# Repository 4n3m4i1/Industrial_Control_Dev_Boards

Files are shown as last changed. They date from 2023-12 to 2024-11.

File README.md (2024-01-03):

# Industrial_Control_Dev_Boards
For many projects a deeply embeddable development board is needed with the capability to take standard industrial DC voltages (12V, 24V, 36V) as input, and reliably provide outputs to anything else in a control/automation system. There aren't great options that support single side mounting (a la Pi Pico) that provide standard peripherals as well as CAN and possibly LIN, so here are some boards!  
  
## Board Families
- Waffle
The Waffle series is based on the F2800154QXXX (C2000 / dual TMS320C28x core) offerings from TI, which are generally aimed at the automotive market and thus provide good interfacing abilities for most controls needs. Several options are offered in the Waffle family (or rather, will, as my needs change) that only vary in pin count.
  
- Curly
The Curly series is based around the RP2040 we all know and love with an integrated TI TCAN4551-Q1 or MCP25625T-E_ML for SPI -> CAN conversion. These ICs include integrated CAN transceivers as well! Dual RS232 channels are provided from the boards, tied to the hardware UART peripherals.

- Tornado
Waiting on the new TI M0+ parts w CAN to drop... (MSPM0G)  
  
## Software Support
Once a design has been fabricated and verified boilerplate project templates will be included in each board's respective directory. Library files for on-board interfaceable components will be generally provided. Ensure required software is installed to reduce any compatability issues.
  
## Using Boards in Designs
Once a design has been fabricated and verified a footprint and symbol (KiCad 7) will be included in its respective library. These can be used as AIO components in other projects easily.
  
## Board Fabrication
Many PCBA services exist, and all fabrication files used to order a board will be provided in their respective directories. JLC's PCBA is unique in that their parts stock is in-house, which can be a massive bonus or immense drag depending on what you're trying to do. For my smaller scale their methods generally work, as long as parts selection is done to best fit their stock (and optimize for "Basic" parts over "Extended" parts, which incurr a proportionally large fee for small runs), as such certain choices have been made to optimize costs. Given their internal parts sourcing anyone can simply use the files provided, click "Buy", and assembled boards will show up at your house.
  
If a board is of interest, but you don't want to order it yourself, please contact me. If there is enough interest the fixed costs for setup and shipping can be reduced massively per board.

- Waffle Mini v0
Not verified.
  
- Curly Mini v0
All files provided for JLC PCBA, can be effectively one click ordered fully assembled. Approx. $45 for 5 complete boards, 1/2 parts, 1/2 setup fees, board costs are negligible. 2 day shipping to CA approx. $18.

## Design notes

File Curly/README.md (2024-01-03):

# Curly
The Curly series is based on the RP2040, which needs no introduction. The simplicity and open nature of the toolchain make this platform ideal in many respects, and the PIO can be leveraged heavily for custom peripheral creation.  
  
[Datasheet/Reference Manual](https://datasheets.raspberrypi.com/rp2040/rp2040-datasheet.pdf)
  
By default a single size of the Curly is offered.
  
## Curly Sizes
- Curly Mini
    - RP2040, 3V3 I/O
    - 44.5mm x 20mm x 1.6mm, 4 layer
    - Single side pinout for vertical mounting in PCB slot
    - 8 GPIO, 4 A2D / GPIO (Total 12) (AREF == 3.3V, not precision ref)
    - External Chip Reset Pin (Active Low)
    - 7V - 48V DC Input Voltage
    - Integrated CAN controller and transceiver (MCP25625T)
    - Integrated 2 channel RS232 converter (MAX3232)
    - NOT breadboard compatible, designed for custom vertical mounting in DIN enclosures
    - Custom 24 pin footprint + symbol provided in library
    - 3 pin Pico/ARM debug and programming interface
    - 3 pin USB 2.0 interface (D+, D-, GND) on header
    - For JLC/LCSC manufacturing the MCP25625T is used as it's more available

## Recommended Software
The `pico-sdk` toolchain should be installed, either via the repository ([pico-sdk](https://github.com/raspberrypi/pico-sdk)), or on Linux systems the clean setup script ([pico_setup.sh](https://github.com/raspberrypi/pico-setup/blob/master/pico_setup.sh)).  
  
## Programming
A standard ARM/Pico 3 pin (SWCLK, SWDIO, GND) JST connector is provided. Using a Pi Pico or other hardware to run picotool / OpenOCD `.elf` files can be loaded into the board, and GDB debugging can be done.
Picotool writeup will come soon...

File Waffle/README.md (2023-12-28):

# Waffle
The Waffle series is based on the F2800154Qxxx family of automotive processors centered around the TMS320C28x processors from TI. While dual core the default behavior is a lockstep mode with hardware comparisons done between each core in order to maintain a higher degree of safety. As with all things this can be customized in software, and disabled to allow full dual core operation if desired.

[Datasheet](https://www.ti.com/lit/gpn/tms320f2800154-q1)
[Reference Manual](https://www.ti.com/lit/ug/spruiy4a/spruiy4a.pdf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)
[Errata](https://www.ti.com/lit/er/sprz507b/sprz507b.pdf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)
  
Different Waffle sizes maintain similar feature sets, with varying amounts of GPIO. Each Waffle board has the following peripheral guaranteed:  
- 1 CAN2.0B / FD
- 3 UART
- 1 LIN
- 10+ PWM Channels

## Waffle Sizes
- Waffle Mini
	- F2800154QRHBRQ1, 20 GPIO
    - 35.56 mm x 17.78 mm
    - 1.4" x 0.7"
    - Breadboard compatible
    - Can be surface mounted w/ castelated pins (single side components)
    - Tag Connect 6 pin cJTAG interface (Odd Even Numbering)
        - 1: 3V3
        - 2: JTAG TMS
        - 3: XRSn (Reset)
        - 4: JTAG TCK
        - 5: GND
        - 6: N/C

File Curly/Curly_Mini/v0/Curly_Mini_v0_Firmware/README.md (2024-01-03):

# Curly Mini v0 Firmware
A boilerplate project with libraries to control the on-board CAN interface (MCP25625T) is provided. Ample use of the `pico-sdk` library functions has been done, please ensure this is properly installed.

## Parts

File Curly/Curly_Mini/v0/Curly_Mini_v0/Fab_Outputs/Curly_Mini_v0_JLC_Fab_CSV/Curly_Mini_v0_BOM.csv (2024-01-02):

Reference | Qty | Value | Footprint | LCSC Part Number
C1, C2, C6, C10, C12, C14, C16, C17, C18, C21, C23, C24, C25, C26, C27, C30, C31, C32, C33 | 19 | 100n | Capacitor_SMD:C_0402_1005Metric | C307331
C3, C4, C5, C9, C11, C13, C15, C19, C29, C34 | 10 | 2u2 | Capacitor_SMD:C_0402_1005Metric | C12530
C7, C8 | 2 | 33p C0G | Capacitor_SMD:C_0402_1005Metric | C1562
C20, C22 | 2 | 10u | Capacitor_SMD:C_0603_1608Metric | C96446
D1 | 1 | LED | LED_SMD:LED_0603_1608Metric | C72043
FB1 | 1 | FB_0603 | Inductor_SMD:L_0603_1608Metric | C1002
J1 | 1 | DEBUG_PORT | Connector_JST:JST_SH_BM03B-SRSS-TB_1x03-1MP_P1.00mm_Vertical | C160389
R1 | 1 | 5k1 | Resistor_SMD:R_0402_1005Metric | C25905
R2 | 1 | 1k 1% | Resistor_SMD:R_0402_1005Metric | C11702
R3, R4 | 2 | 27R | Resistor_SMD:R_0402_1005Metric | C25092
R5 | 1 | 330R | Resistor_SMD:R_0402_1005Metric | C25104
U1 | 1 | RP2040 | Package_DFN_QFN:QFN-56-1EP_7x7mm_P0.4mm_EP3.2x3.2mm | C2040
U2 | 1 | MCP25625T-E_ML | ICDB_Curly:QFN65P600X600X100-29N | C191253
U3 | 1 | XC6206PxxxMR | Package_TO_SOT_SMD:SOT-23-3 | C5446
U4 | 1 | W25Q16JVUXIQ_TR | ICDB_Curly:IC_W25Q16JVUXIQ_TR | C2843335
U5 | 1 | SE8650X2-HF | Package_TO_SOT_SMD:SOT-23-3 | C496615
U6 | 1 | MAX3232 | Package_SO:TSSOP-16_4.4x5mm_P0.65mm | C11317
Y2 | 1 | 12.000 MHz, C9002 | Crystal:Crystal_SMD_3225-4Pin_3.2x2.5mm | C9002

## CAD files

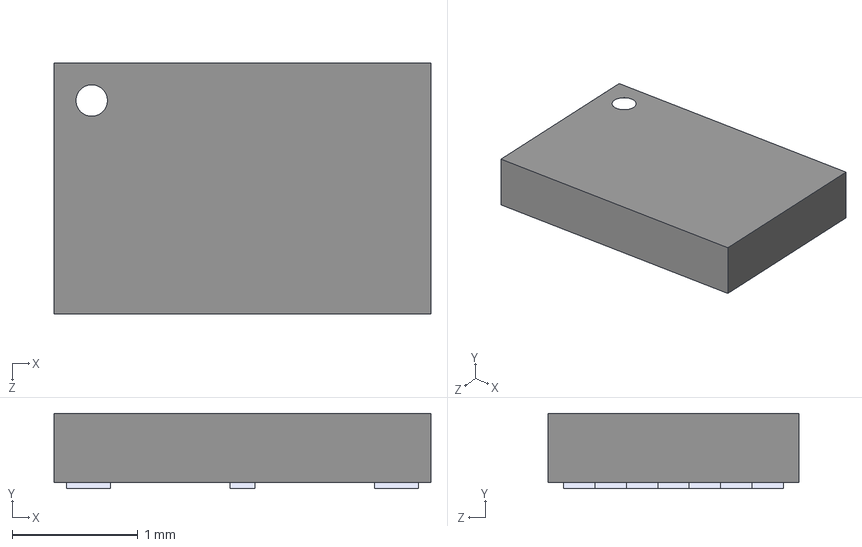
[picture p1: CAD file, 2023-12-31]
icdb_KiCad_7_Libs/ICDB_Curly/W25Q16JVUXIQ_TR.step
3.00 x 0.6 x 2.00 mm

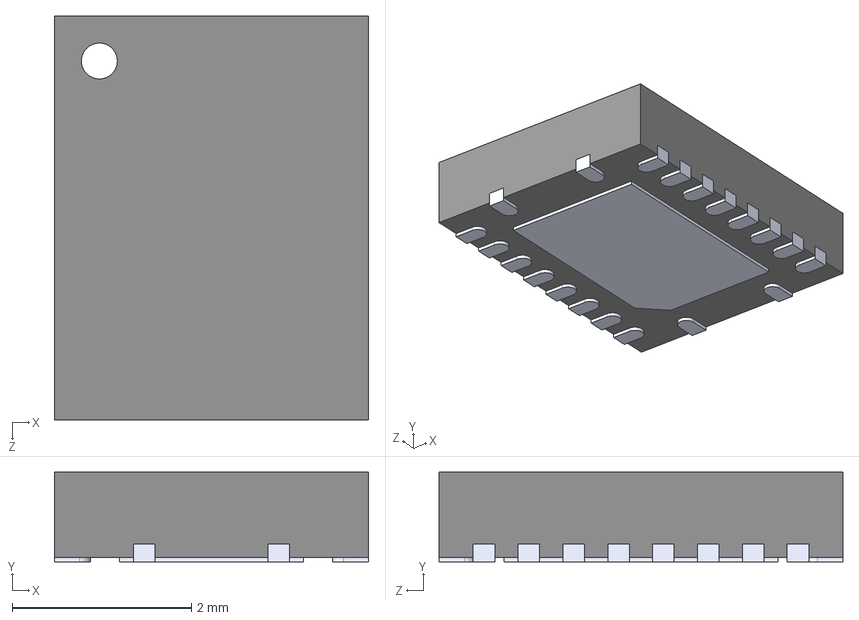
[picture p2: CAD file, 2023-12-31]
icdb_KiCad_7_Libs/ICDB_Curly/TCAN4550RGYRQ1.step
3.50 x 1.00 x 4.50 mm

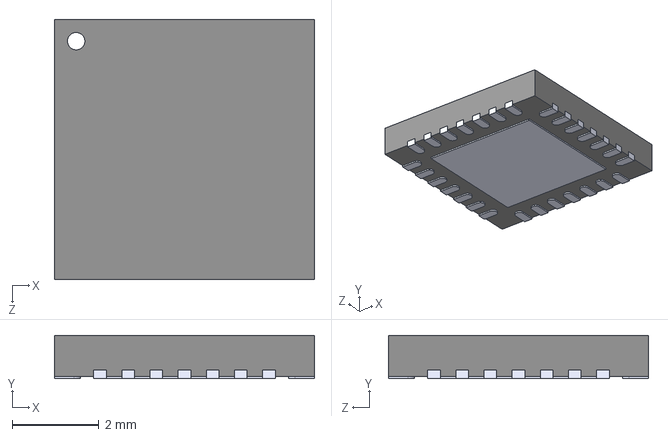
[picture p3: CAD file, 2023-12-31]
icdb_KiCad_7_Libs/ICDB_Curly/MCP25625T-E_ML.step
6.00 x 1.00 x 6.00 mm

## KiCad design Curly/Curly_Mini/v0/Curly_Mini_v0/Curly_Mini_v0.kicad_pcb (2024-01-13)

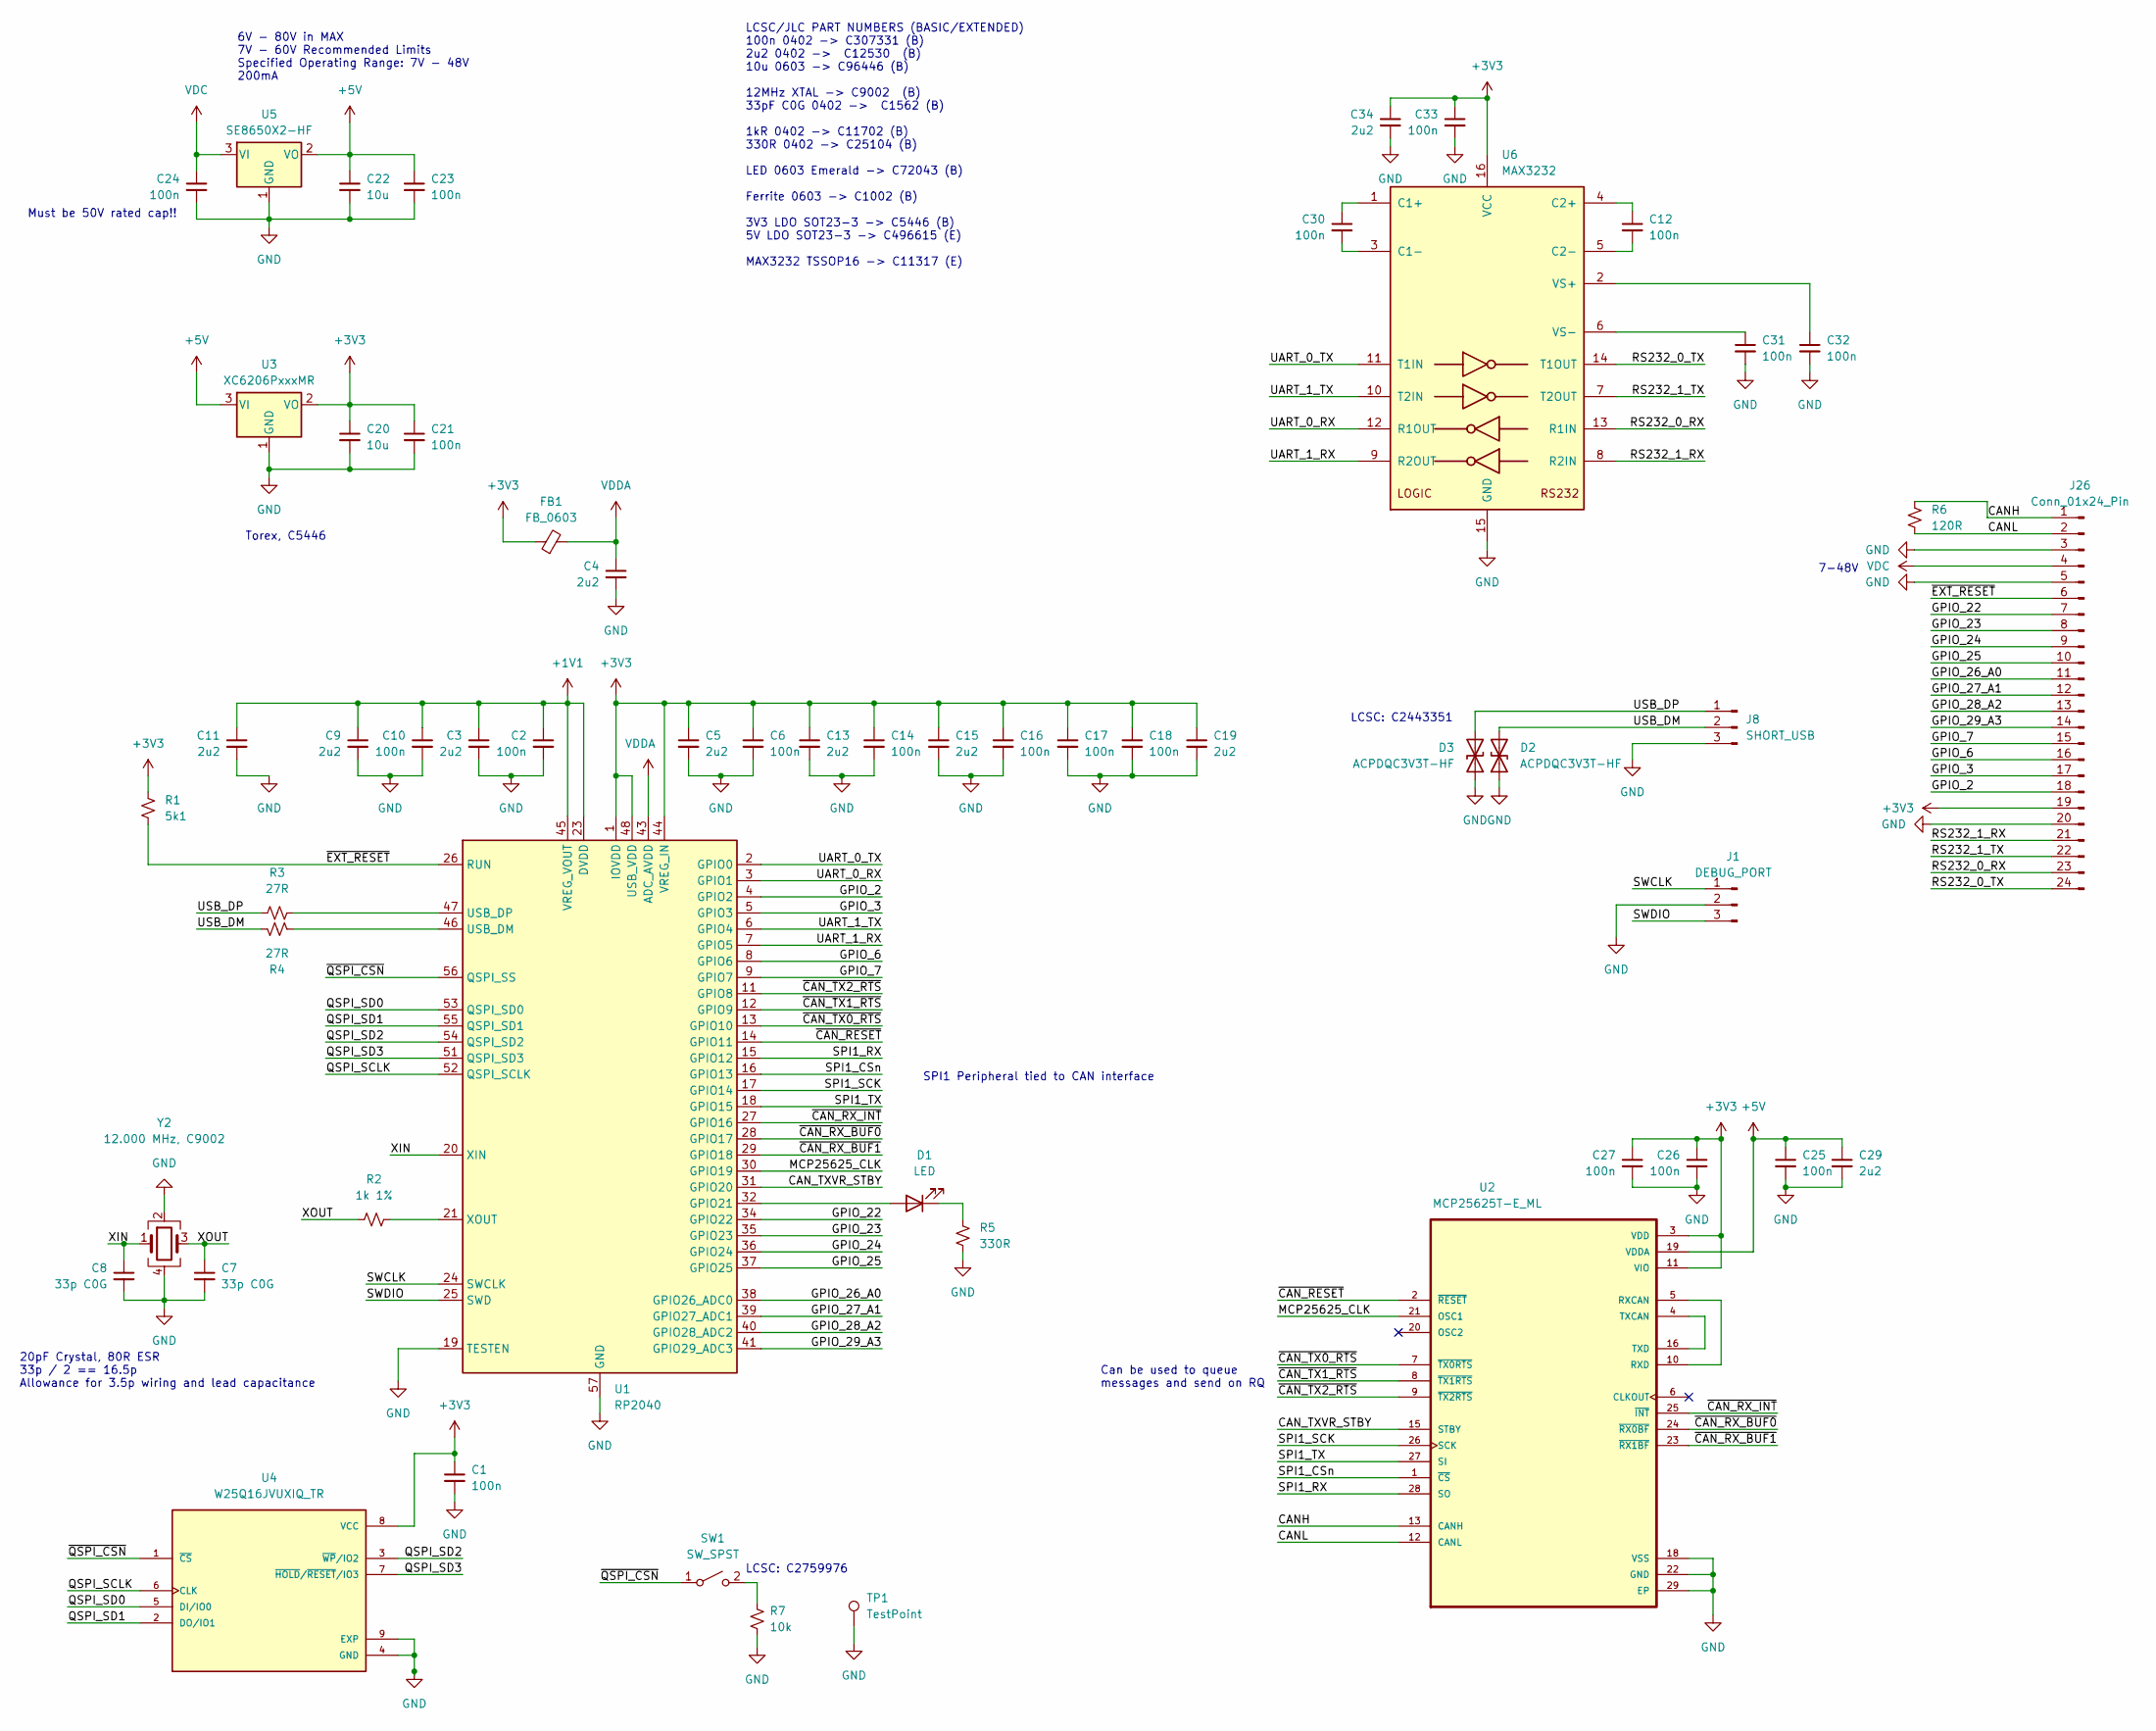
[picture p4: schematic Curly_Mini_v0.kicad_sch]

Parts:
C1, C2, C6, C10, C12, C14, C16, C17, C18, C21, C23, C24, C25, C26, C27, C30, C31, C32, C33: 100n; C_0402_1005Metric
C3, C4, C5, C9, C11, C13, C15, C19, C29, C34: 2u2; C_0402_1005Metric
C7, C8: 33p C0G; C_0402_1005Metric
C20, C22: 10u; C_0603_1608Metric
D1: LED; LED_0603_1608Metric
D2, D3: ACPDQC3V3T-HF; 0402C-SOD-923F
FB1: FB_0603; L_0603_1608Metric
J1: DEBUG_PORT; JST_SH_BM03B-SRSS-TB_1x03-1MP_P1.00mm_Vertical
J8: SHORT_USB; PinSocket_1x03_P2.54mm_Vertical
J26: Conn_01x24_Pin; ICDB_Curly_Edge_Conn
R1: 5k1; R_0402_1005Metric
R2: 1k 1%; R_0402_1005Metric
R3, R4: 27R; R_0402_1005Metric
R5: 330R; R_0402_1005Metric
R6: 120R; R_0805_2012Metric_Pad1.20x1.40mm_HandSolder
R7: 10k; R_0402_1005Metric
SW1: SW_SPST; TPS850 J14Q V SMTR LFS
TP1: TestPoint; TestPoint_Pad_D2.0mm
U1: RP2040; QFN-56-1EP_7x7mm_P0.4mm_EP3.2x3.2mm
U2: MCP25625T-E_ML; QFN65P600X600X100-29N; DIGI-KEY_PART_NUMBER MCP25625T-E/MLCT-ND
U3: XC6206PxxxMR; SOT-23-3
U4: W25Q16JVUXIQ_TR; IC_W25Q16JVUXIQ_TR; PARTREV H
U5: SE8650X2-HF; SOT-23-3
U6: MAX3232; TSSOP-16_4.4x5mm_P0.65mm
Y2: 12.000 MHz, C9002; Crystal_SMD_3225-4Pin_3.2x2.5mm

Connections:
+1V1: C2.1, C3.1, C9.1, C10.1, C11.1, U1.23 (DVDD), U1.45 (VREG_VOUT), U1.50 (DVDD)
+3V3: C1.1, C5.1, C6.1, C13.1, C14.1, C15.1, C16.1, C17.1, C18.1, C19.1, C20.1, C21.1, C26.1, C27.1, C33.1, C34.1, FB1.1, J26.19, R1.1, U1.1 (IOVDD), U1.10 (IOVDD), U1.22 (IOVDD), U1.33 (IOVDD), U1.42 (IOVDD), U1.44 (VREG_IN), U1.48 (USB_VDD), U1.49 (IOVDD), U2.3 (VDD), U2.11 (VIO), U3.2 (VO), U4.8 (VCC), U6.16 (VCC)
+5V: C22.1, C23.1, C25.1, C29.1, U2.19 (VDDA), U3.3 (VI), U5.2 (VO)
/CANH: J26.1, R6.1, U2.13 (CANH)
/CANL: J26.2, R6.2, U2.12 (CANL)
/CAN_TXVR_STBY: U1.31 (GPIO20), U2.15 (STBY)
/GPIO_2: J26.18, U1.4 (GPIO2)
/GPIO_3: J26.17, U1.5 (GPIO3)
/GPIO_6: J26.16, U1.8 (GPIO6)
/GPIO_7: J26.15, U1.9 (GPIO7)
/GPIO_22: J26.7, U1.34 (GPIO22)
/GPIO_23: J26.8, U1.35 (GPIO23)
/GPIO_24: J26.9, U1.36 (GPIO24)
/GPIO_25: J26.10, U1.37 (GPIO25)
/GPIO_26_A0: J26.11, U1.38 (GPIO26_ADC0)
/GPIO_27_A1: J26.12, U1.39 (GPIO27_ADC1)
/GPIO_28_A2: J26.13, U1.40 (GPIO28_ADC2)
/GPIO_29_A3: J26.14, U1.41 (GPIO29_ADC3)
/MCP25625_CLK: U1.30 (GPIO19), U2.21 (OSC1)
/QSPI_SCLK: U1.52 (QSPI_SCLK), U4.6 (CLK)
/QSPI_SD0: U1.53 (QSPI_SD0), U4.5 (DI/IO0)
/QSPI_SD1: U1.55 (QSPI_SD1), U4.2 (DO/IO1)
/QSPI_SD2: U1.54 (QSPI_SD2), U4.3 (~WP/IO2)
/QSPI_SD3: U1.51 (QSPI_SD3), U4.7 (~HOLD/~RESET/IO3)
/RS232_0_RX: J26.23, U6.13 (R1IN)
/RS232_0_TX: J26.24, U6.14 (T1OUT)
/RS232_1_RX: J26.21, U6.8 (R2IN)
/RS232_1_TX: J26.22, U6.7 (T2OUT)
/SPI1_CSn: U1.16 (GPIO13), U2.1 (~CS)
/SPI1_RX: U1.15 (GPIO12), U2.28 (SO)
/SPI1_SCK: U1.17 (GPIO14), U2.26 (SCK)
/SPI1_TX: U1.18 (GPIO15), U2.27 (SI)
/SWCLK: J1.1, U1.24 (SWCLK)
/SWDIO: J1.3, U1.25 (SWD)
/UART_0_RX: U1.3 (GPIO1), U6.12 (R1OUT)
/UART_0_TX: U1.2 (GPIO0), U6.11 (T1IN)
/UART_1_RX: U1.7 (GPIO5), U6.9 (R2OUT)
/UART_1_TX: U1.6 (GPIO4), U6.10 (T2IN)
/USB_DM: D2.2 (A2), J8.2, R4.1
/USB_DP: D3.2 (A2), J8.1, R3.1
/XIN: C8.1, U1.20 (XIN), Y2.1
/XOUT: C7.1, R2.1, Y2.3
/~CAN_RESET: U1.14 (GPIO11), U2.2 (~RESET)
/~CAN_RX_BUF0: U1.28 (GPIO17), U2.24 (~RX0BF)
/~CAN_RX_BUF1: U1.29 (GPIO18), U2.23 (~RX1BF)
/~CAN_RX_INT: U1.27 (GPIO16), U2.25 (~INT)
/~CAN_TX0_RTS: U1.13 (GPIO10), U2.7 (~TX0RTS)
/~CAN_TX1_RTS: U1.12 (GPIO9), U2.8 (~TX1RTS)
/~CAN_TX2_RTS: U1.11 (GPIO8), U2.9 (~TX2RTS)
/~EXT_RESET: J26.6, R1.2, U1.26 (RUN)
/~QSPI_CSN: SW1.1 (A), U1.56 (QSPI_SS), U4.1 (~CS)
GND: C1.2, C2.2, C3.2, C4.2, C5.2, C6.2, C7.2, C8.2, C9.2, C10.2, C11.2, C13.2, C14.2, C15.2, C16.2, C17.2, C18.2, C19.2, C20.2, C21.2, C22.2, C23.2, C24.2, C25.2, C26.2, C27.2, C29.2, C31.2, C32.2, C33.2, C34.2, D2.1 (A1), D3.1 (A1), J1.2, J8.3, J26.3, J26.5, J26.20, R5.2, R7.2, TP1.1, U1.19 (TESTEN), U1.57 (GND), U2.18 (VSS), U2.22 (GND), U2.29 (EP), U3.1 (GND), U4.4 (GND), U4.9 (EXP), U5.1 (GND), U6.15 (GND), Y2.2, Y2.4
unnamed: D1.2 (A), U1.32 (GPIO21)
unnamed: D1.1 (K), R5.1
unnamed: R7.1, SW1.2 (B)
unnamed: R4.2, U1.46 (USB_DM)
unnamed: R3.2, U1.47 (USB_DP)
unnamed: R2.2, U1.21 (XOUT)
unnamed: U2.5 (RXCAN), U2.10 (RXD)
unnamed: U2.4 (TXCAN), U2.16 (TXD)
unnamed: C30.1, U6.1 (C1+)
unnamed: C30.2, U6.3 (C1-)
unnamed: C12.1, U6.4 (C2+)
unnamed: C12.2, U6.5 (C2-)
unnamed: C32.1, U6.2 (VS+)
unnamed: C31.1, U6.6 (VS-)
VDC: C24.1, J26.4, U5.3 (VI)
VDDA: C4.1, FB1.2, U1.43 (ADC_AVDD)

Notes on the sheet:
Must be 50V rated cap!!
20pF Crystal, 80R ESR 33p / 2 == 16.5p Allowance for 3.5p wiring and lead capacitance
Torex, C5446
SPI1 Peripheral tied to CAN interface
Can be used to queue messages and send on RQ
LCSC: C2443351
LCSC/JLC PART NUMBERS (BASIC/EXTENDED) 100n 0402 -> C307331 (B) 2u2 0402 -> C12530 (B) 10u 0603 -> C96446 (B) 12MHz XTAL -> C9002 (B) 33pF C0G 0402 -> C1562 (B) 1kR 0402 -> C11702 (B) 330R 0402 -> C25104 (B) LED 0603 Emerald -> C72043 (B) Ferrite 0603 -> C1002 (B) 3V3 LDO SOT23-3 -> C5446 (B) 5V LD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
LCSC: C2759976
6V - 80V in MAX 7V - 60V Recommended Limits Specified Operating Range: 7V - 48V 200mA
7-48V

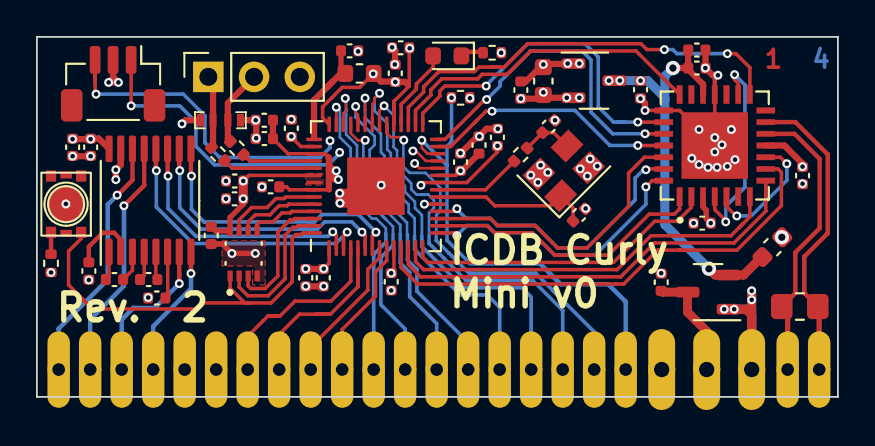
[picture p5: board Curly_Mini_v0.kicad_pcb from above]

Board: 4 copper layers, 44.5 x 20.0 mm, 56 parts (0 on the bottom side), 68 nets.

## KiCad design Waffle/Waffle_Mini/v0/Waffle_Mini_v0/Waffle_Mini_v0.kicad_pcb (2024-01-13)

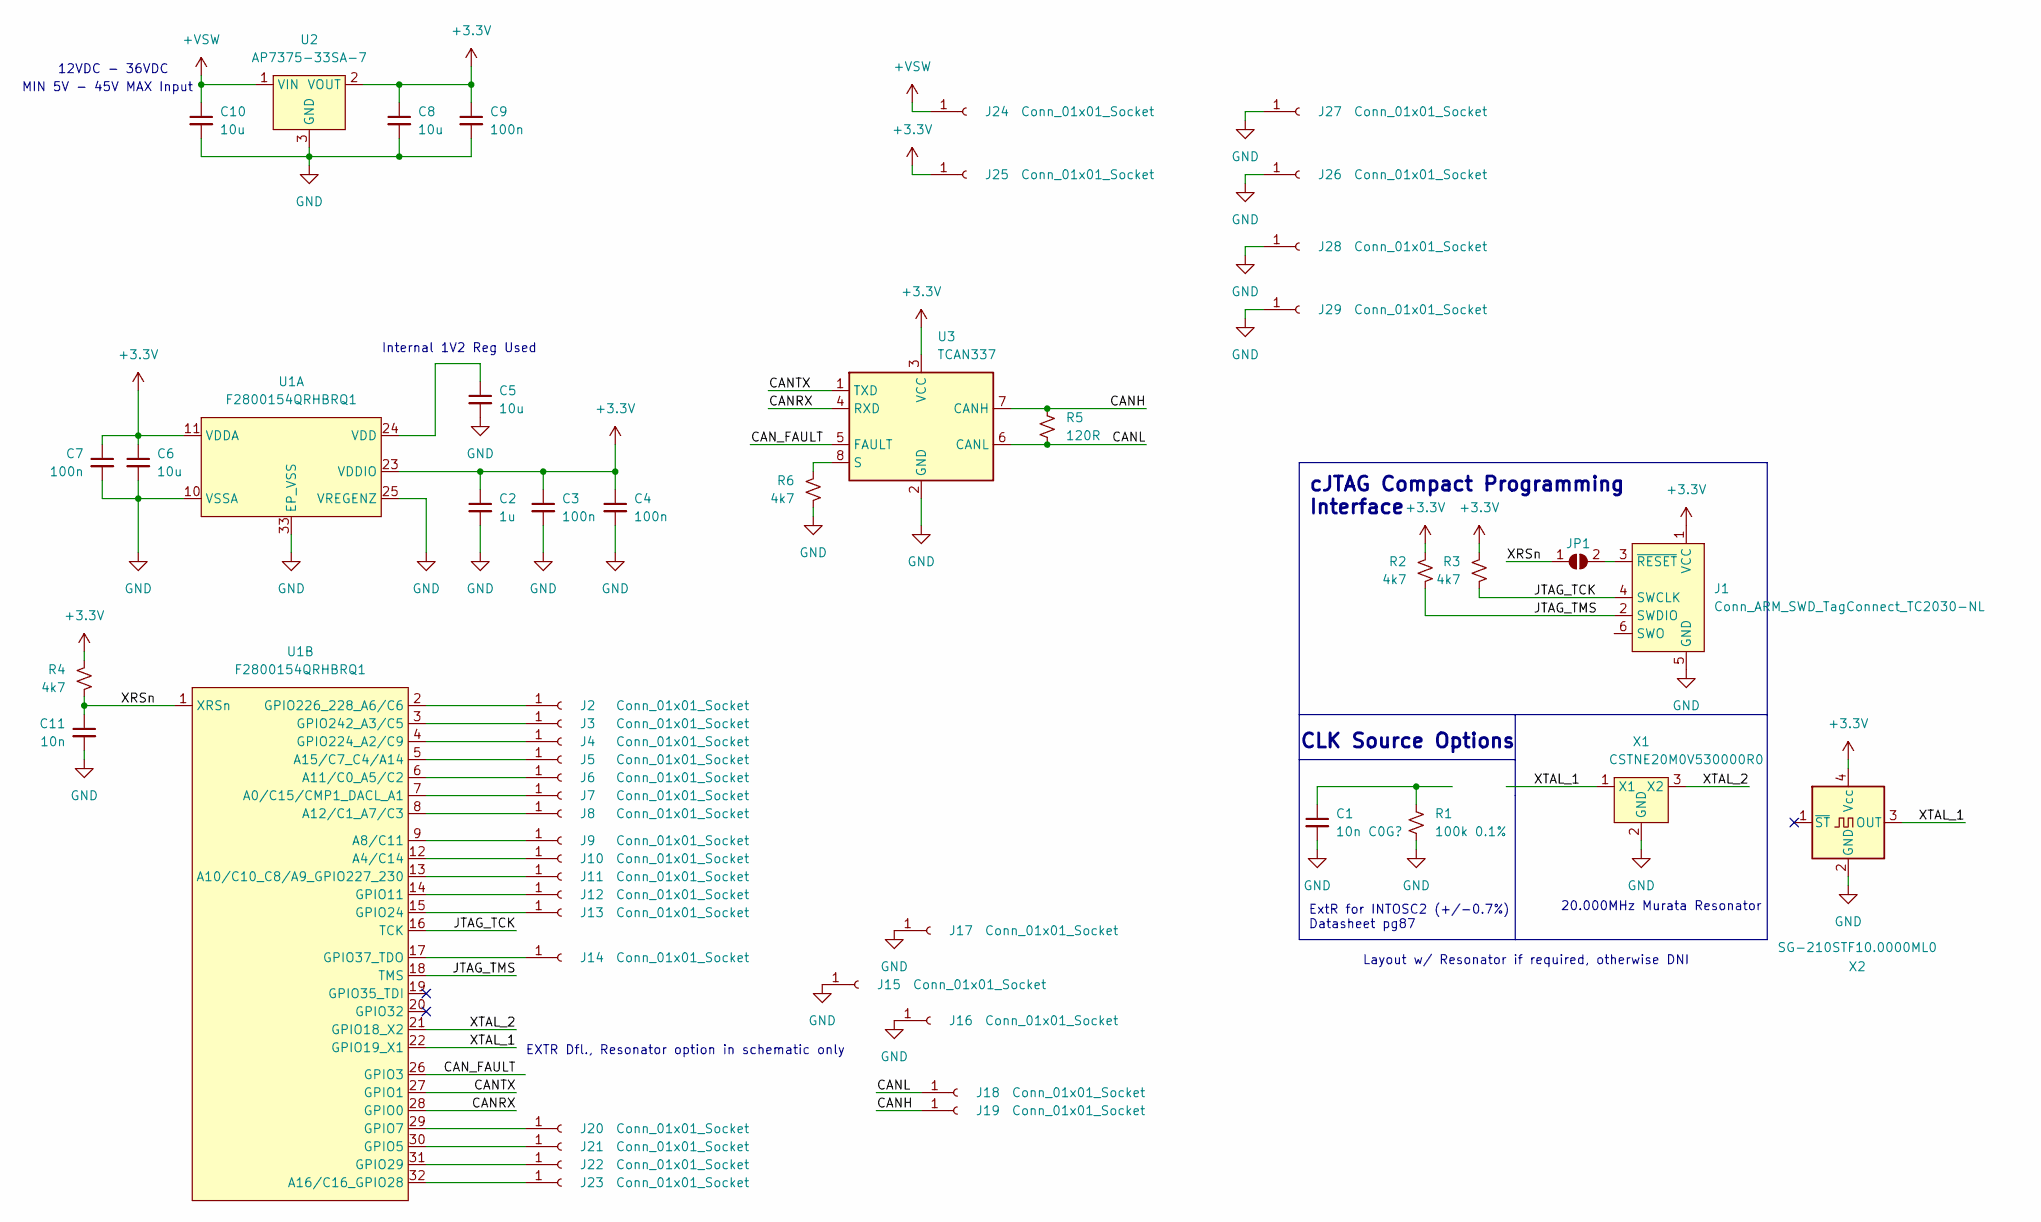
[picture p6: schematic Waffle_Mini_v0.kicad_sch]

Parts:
C1: 10n C0G?; C_0603_1608Metric
C2: 1u; C_0805_2012Metric
C3, C4, C7, C9: 100n; C_0603_1608Metric
C5, C6, C8: 10u; C_0805_2012Metric
C10: 10u; C_1210_3225Metric
C11: 10n; C_0603_1608Metric
J1: Conn_ARM_SWD_TagConnect_TC2030-NL; Tag-Connect_TC2030-IDC-NL_2x03_P1.27mm_Vertical
J2, J3, J4, J5, J6, J7, J8, J9, J10, J11, J12, J13, J14, J15, J16, J17, J18, J19, J20, J21, J22, J23, J24, J25, J26, J27, J28, J29: Conn_01x01_Socket; ICDB_Castellated_Pad
JP1: SolderJumper_2_Open; SolderJumper-2_P1.3mm_Open_TrianglePad1.0x1.5mm
R1: 100k 0.1%; R_0603_1608Metric
R2, R3, R4, R6: 4k7; R_0603_1608Metric
R5: 120R; R_0805_2012Metric
U1: F2800154QRHBRQ1; VQFN-32-1EP_5x5mm_P0.5mm_EP3.15x3.15mm
U2: AP7375-33SA-7; SOT-23-3
U3: TCAN337; SOT-23-8
X1: CSTNE20M0V530000R0; CSTNE_Murata_Resonator
X2: SG-210STF10.0000ML0; Oscillator_SMD_SeikoEpson_SG210-4Pin_2.5x2.0mm

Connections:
+3.3V: C2.1, C3.1, C4.1, C6.1, C7.1, C8.1, C9.1, J1.1 (VCC), J25.1, R2.1, R3.1, R4.1, U1.11 (VDDA), U1.23 (VDDIO), U2.2 (VOUT), U3.3 (VCC), X2.4 (Vcc)
+VSW: C10.1, J24.1, U2.1 (VIN)
/CANH: J19.1, R5.1, U3.7 (CANH)
/CANL: J18.1, R5.2, U3.6 (CANL)
/CANRX: U1.28 (GPIO0), U3.4 (RXD)
/CANTX: U1.27 (GPIO1), U3.1 (TXD)
/CAN_FAULT: U1.26 (GPIO3), U3.5 (FAULT)
/JTAG_TCK: J1.4 (SWCLK), R3.2, U1.16 (TCK)
/JTAG_TMS: J1.2 (SWDIO), R2.2, U1.18 (TMS)
/XRSn: C11.1, JP1.1 (A), R4.2, U1.1 (XRSn)
/XTAL_1: U1.22 (GPIO19_X1), X1.1 (X1), X2.3 (OUT)
/XTAL_2: U1.21 (GPIO18_X2), X1.3 (X2)
GND: C1.2, C2.2, C3.2, C4.2, C5.2, C6.2, C7.2, C8.2, C9.2, C10.2, C11.2, J1.5 (GND), J15.1, J16.1, J17.1, J26.1, J27.1, J28.1, J29.1, R1.2, R6.2, U1.10 (VSSA), U1.25 (VREGENZ), U1.33 (EP_VSS), U2.3 (GND), U3.2 (GND), X1.2 (GND), X2.2 (GND)
unnamed: C1.1, R1.1
unnamed: J1.3 (~RESET), JP1.2 (B)
unnamed: J2.1, U1.2 (GPIO226_228_A6/C6)
unnamed: J3.1, U1.3 (GPIO242_A3/C5)
unnamed: J4.1, U1.4 (GPIO224_A2/C9)
unnamed: J5.1, U1.5 (A15/C7_C4/A14)
unnamed: J6.1, U1.6 (A11/C0_A5/C2)
unnamed: J7.1, U1.7 (A0/C15/CMP1_DACL_A1)
unnamed: J8.1, U1.8 (A12/C1_A7/C3)
unnamed: J9.1, U1.9 (A8/C11)
unnamed: J10.1, U1.12 (A4/C14)
unnamed: J11.1, U1.13 (A10/C10_C8/A9_GPIO227_230)
unnamed: J12.1, U1.14 (GPIO11)
unnamed: J13.1, U1.15 (GPIO24)
unnamed: J14.1, U1.17 (GPIO37_TDO)
unnamed: J20.1, U1.29 (GPIO7)
unnamed: J21.1, U1.30 (GPIO5)
unnamed: J22.1, U1.31 (GPIO29)
unnamed: J23.1, U1.32 (A16/C16_GPIO28)
unnamed: C5.1, U1.24 (VDD)
unnamed: R6.1, U3.8 (S)

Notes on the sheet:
ExtR for INTOSC2 (+/-0.7%) Datasheet pg87
EXTR Dfl., Resonator option in schematic only
CLK Source Options
Layout w/ Resonator if required, otherwise DNI
12VDC - 36VDC
Internal 1V2 Reg Used
cJTAG Compact Programming Interface
MIN 5V - 45V MAX Input
20.000MHz Murata Resonator

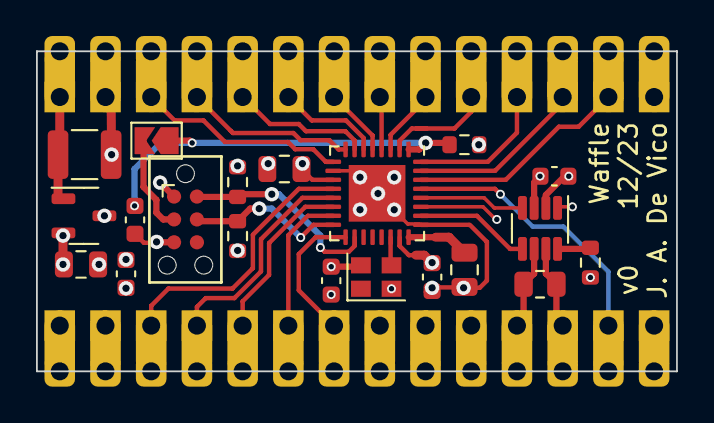
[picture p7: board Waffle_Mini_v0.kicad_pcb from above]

Board: 4 copper layers, 35.6 x 17.8 mm, 48 parts (0 on the bottom side), 32 nets.

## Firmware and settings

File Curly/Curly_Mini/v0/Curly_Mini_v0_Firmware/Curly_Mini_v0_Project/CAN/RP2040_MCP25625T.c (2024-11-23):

#include "RP2040_MCP25625T.h"
// pico-sdk
#include "pico/stdlib.h"
#include "hardware/pwm.h"
#include "hardware/spi.h"



void MCP25625_Setup(spi_inst_t *spi, uint sck_pin, uint cs_pin, uint spi_rx, uint spi_tx, uint can_baud, uint can_clk_pin){
    spi_init(spi, MCP25625_SPI_HZ);     // 10MHz
    
    gpio_init(cs_pin);
    gpio_set_dir(cs_pin, GPIO_OUT);
    gpio_pull_up(cs_pin);               // Pullup just in case
    gpio_put(cs_pin, true);                // CS is active low

    gpio_set_function(sck_pin, GPIO_FUNC_SPI);
    gpio_set_function(spi_rx, GPIO_FUNC_SPI);
    gpio_set_function(spi_tx, GPIO_FUNC_SPI);

    spi_get_hw(spi)->SSPCR0 &= ~(0x000F);   // Clear data width
    spi_get_hw(spi)->SSPCR0 |= 0x0007;      // set to 8 bit txfr widths

    // Setup other CAN GPIO stuff for ISRs and external reset.
    //  Much of this functionality can be done with the SPI interface,
    //      and will be removed in future revisions
#ifdef CURLY_MINI_v0
    gpio_init(CAN_RESET);
    gpio_set_dir(CAN_RESET, GPIO_OUT);
    gpio_put(CAN_RESET, true);

    gpio_init(CAN_TX2_RTS);
    gpio_set_dir(CAN_TX2_RTS, GPIO_OUT);
    gpio_put(CAN_TX2_RTS, true);
    gpio_init(CAN_TX1_RTS);
    gpio_set_dir(CAN_TX1_RTS, GPIO_OUT);
    gpio_put(CAN_TX1_RTS, true);
    gpio_init(CAN_TX0_RTS);
    gpio_set_dir(CAN_TX0_RTS, GPIO_OUT);
    gpio_put(CAN_TX0_RTS, true);

    gpio_init(CAN_RX_INT);
    gpio_set_dir(CAN_RX_INT, GPIO_IN);
    gpio_pull_up(CAN_RX_INT);

    gpio_init(CAN_RX_BUF0);
    gpio_set_dir(CAN_RX_BUF0, GPIO_IN);
    gpio_pull_up(CAN_RX_BUF0);

    gpio_init(CAN_RX_BUF1);
    gpio_set_dir(CAN_RX_BUF1, GPIO_IN);
    gpio_pull_up(CAN_RX_BUF1);
#endif
    gpio_put(CAN_RESET, false);

    gpio_init(can_clk_pin);
    gpio_set_dir(can_clk_pin, GPIO_OUT);
    // Setup CAN Clk @ 20MHz
    //  RP2040 base clock assumed to be 125MHz
    //  125M / 20M = 6.25
    //      Int = 6
    //      Frac is 4 bit fixed pt: .5, .25, .125, .0625
    //      Frac = 1 << 2
    // BUT divide by 2 since we need to run PWM, so:
    //      Int = 3
    //      Frac = .125 = (1 << 1)
    gpio_set_function(can_clk_pin, GPIO_FUNC_PWM);
    uint sliceno = pwm_gpio_to_slice_num(can_clk_pin);
    uint pwmchan = pwm_gpio_to_channel(can_clk_pin);
    pwm_set_chan_level(sliceno, pwmchan, 1);
    pwm_set_wrap(sliceno, 2);
    pwm_set_clkdiv_int_frac(sliceno, 3, (1 << 1));
    pwm_set_enabled(sliceno, true);

    // Finish boot reset
    gpio_put(CAN_RESET, true);

    // Now we need to setup the CAN bit clock... ew
}

// spi_write_read_blocking(spi_inst_t *spi, const uint8_t *src, uint8_t *dst, size_t len)
uint8_t MCP25625_Read_Blocking(spi_inst_t *spi ,uint8_t address){
    uint8_t tval[3]; 
    tval[0] = CAN_CTRL_READ; 
    tval[1] = address;
    uint8_t rval[3];
    spi_write_read_blocking(spi, tval, rval, sizeof(tval));
    return rval[2];
}

void MCP25625_CAN_Message_2_Raw_Arr(uint8_t *arr, struct CAN_Message *msg){
    if(msg && arr){
        arr[XBnDLC] = (msg->len & 0x0F);   // Set len
        arr[XBnSIDH] = ((msg->id >> 3) & 0x0F);
        arr[XBnSIDL] = ((msg->id & 0x07) << 5);
        if(msg->flags.ext){
            arr[XBnSIDL] |= (1 << 3);   // set extended
            arr[XBnSIDL] |= ((msg->id >> (16 + STDIDLEN)) & 0x03);
            arr[XBnEID8] =  (msg->id >> (8 + STDIDLEN));
            arr[XBnEID0] =  (msg->id >> (0 + STDIDLEN));
            arr[XBnDLC]  |= ((msg->flags.ext) ? (1 << 6) : 0);  // ext rtr
        } else {
            arr[XBnSIDL] |= (((msg->flags.remote) ? 1 : 0) << 4);
        }

        for(int n = 0; n < msg->len; ++n) arr[XBnD0 + n] = msg->data[n];
    }
}

void MCP25625_Raw_Arr_2_CAN_Message(struct CAN_Message *msg, uint8_t *arr){
    if(msg && arr){
        msg->id = (arr[XBnSIDL] >> 5) | arr[XBnSIDH];
        msg->flags.ext = arr[XBnSIDL] & (1 << 3);
        if(msg->flags.ext){
            msg->id |= (arr[XBnSIDL] & 0x03) << (16 + STDIDLEN);
            msg->id |= (arr[XBnEID8] << (8 + STDIDLEN));
            msg->id |= (arr[XBnEID0] << (0 + STDIDLEN));

            msg->flags.remote = arr[XBnDLC] & (1 << 6);
        } else {
            msg->flags.remote = arr[XBnSIDL] & (1 << 4);
        }

        msg->len = (arr[XBnDLC] & 0xF);

        for(int n = 0; n < msg->len; ++n) msg->data[n] = arr[XBnD0 + n]; 
    }
}

uint8_t MCP25625_Read_RX_Buffer_Blocking(spi_inst_t *spi, struct CAN_Message *msg, uint8_t buff_num){
    uint8_t tval[13]; 
    tval[0] = CAN_READ_RX_BUFF | buff_num; 
    uint8_t rval[13];
    // Starting transfer from top of RXBxSIDH -> 13 bytes total read
    //  Starting transfer from top of data field -> 8 bytes total read
    //  13 - 8 = 5
    if(buff_num & 0x01){    // Full read
        spi_write_read_blocking(spi, tval, rval, sizeof(tval));
        MCP25625_Raw_Arr_2_CAN_Message(msg, rval);
    } else {                // Just Data Read
        spi_write_read_blocking(spi, tval, rval, sizeof(tval) - MCP_MAILBOX_D0_OFFSET);
        for(int n = 0; n < 8; ++n) msg->data[n] = rval[n];
    }
    
    
    return rval[1];
}

// int spi_write_blocking(spi_inst_t *spi, const uint8_t *src, size_t len);
void MCP25625_Write_Blocking(spi_inst_t *spi, uint8_t address, uint8_t data){
    uint8_t tval[3];
    tval[0] = CAN_CTRL_WRITE;
    tval[1] = address;
    tval[2] = data;
    spi_write_blocking(spi, tval, sizeof(tval));
}

void MCP25625_Write_TX_Buffer_Blocking(spi_inst_t *spi, uint8_t buff_num, uint8_t data){
    uint8_t tval[2];
    tval[0] = CAN_LOAD_TX_BUFF | buff_num;
    tval[1] = data;
    spi_write_blocking(spi, tval, sizeof(tval));
}

void MCP25625_RTS_Blocking(spi_inst_t *spi, uint8_t buff_num){
    uint8_t tval = CAN_CTRL_RTS | buff_num;
    spi_write_blocking(spi, tval, sizeof(tval));
}

void MCP25625_Bit_Modify_Blocking(spi_inst_t *spi, uint8_t addr, uint8_t mask, uint8_t data){
    uint8_t tval[4];
    tval[0] = CAN_CTRL_WRITE;
    tval[1] = addr;
    tval[2] = mask;
    tval[3] = data;
    spi_write_blocking(spi, tval, sizeof(tval));
}

uint8_t MCP25625_Read_Status_Blocking(spi_inst_t *spi){
    uint8_t tval[3]; 
    tval[0] = CAN_READ_STATUS; 
    uint8_t rval[3];
    spi_write_read_blocking(spi, tval, rval, sizeof(tval));
    return rval[2]; // bytes [1] and [2] are the same
}

uint8_t MCP25625_Read_RX_Buff_Status_Blocking(spi_inst_t *spi){
    uint8_t tval[3]; 
    tval[0] = CAN_RX_BUFF_STATUS; 
    uint8_t rval[3];
    spi_write_read_blocking(spi, tval, rval, sizeof(tval));
    return rval[2]; // bytes [1] and [2] are the same
}

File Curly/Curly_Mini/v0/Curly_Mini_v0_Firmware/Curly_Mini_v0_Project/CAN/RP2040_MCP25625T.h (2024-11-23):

#ifndef RP2040_MCP25625_h
#define RP2040_MCP25625_h

#include "pico/stdlib.h"
#include "hardware/spi.h"
#include <inttypes.h>

// MCP25625 SPI Interface
/*
    CS Low -> {INSTRUCTION / COMMAND BYTE}
    Another command can't be set until CS is raised.

    Mode 0,0 and Mode 1,1 Supported
        (Data ingested on RISING, Data shifted on FALLING)
*/

// 10 MHz
#define MCP25625_SPI_HZ         (10 * 1000 * 1000)

// MCP25625 SPI Interface Commands
//  Datasheet Section 5 (pg 55)
#define CAN_CTRL_RESET          0xC0    // Equivalent to pin RESET
#define CAN_CTRL_READ           0x03
#define CAN_CTRL_WRITE          0x02
#define CAN_CTRL_RTS            0x80    // Set bits 0,1,2 for which TXB to send
#define CAN_BIT_MODIFY          0x05

// Quick Status Read, Controller/System Status
#define CAN_READ_STATUS         0xA0
enum CAN_READ_STATUS_BITS {
    RX0IF,
    RX1IF,
    TXREQ,
    TX0IF,
    TXREQ,
    TX1IF,
    TXREQ,
    TX2IF
};

// RX Information status
#define CAN_RX_BUFF_STATUS      0xB0
    // Masks for RX Status return
#define RXBUFSTAT_RX_MSG_OFFSET     6
#define RXBUFSTAT_RX_MSG_MASK       ((1 << 7) | (1 << 6))
enum RXBUFSTAT_RX_MSG_FIELD {
    RXBUFSTAT_NO_MESSAGE,
    RXBUFSTAT_MSG_IN_RXB0       = (1 << RXBUFSTAT_RX_MSG_OFFSET),
    RXBUFSTAT_MSG_IN_RXB1       = (2 << RXBUFSTAT_RX_MSG_OFFSET),
    RXBUFSTAT_MSG_IN_BOTH       = (3 << RXBUFSTAT_RX_MSG_OFFSET)
};

#define RXBUFSTAT_MSG_TYPE_OFFSET   3
#define RXBUFSTAT_MSG_TYPE_MASK     ((1 << 4) | (1 << 3))
enum RXBUFSTAT_MSG_TYPE_FIELD {
    RXBUFSTAT_STD_DATA_FRAME,
    RXBUFSTAT_STD_REMOTE_FRAME  = (1 << RXBUFSTAT_MSG_TYPE_OFFSET),
    RXBUFSTAT_EXT_DATA_FRAME    = (2 << RXBUFSTAT_MSG_TYPE_OFFSET),
    RXBUFSTAT_EXT_REMOTE_FRAME  = (3 << RXBUFSTAT_MSG_TYPE_OFFSET)
};

#define RXBUFSTAT_FILT_MATCH_OFFSET 0
#define RXBUFSTAT_FILT_MATCH_MASK   ((1 << 2) | (1 << 1) | (1 << 0))
enum RXBUFSTAT_FILT_MATCH_FIELD {
    MATCH_RXF0,
    MATCH_RXF1,
    MATCH_RXF2,
    MATCH_RXF3,
    MATCH_RXF4,
    MATCH_RXF5,
    MATCH_RXF0_ROLLOVER,
    MATCH_RXF1_ROLLOVER
};

// Quick Message Instructions
#define CAN_LOAD_TX_BUFF        0x40    // Set low 3 bits (0 - 5) to directly load TXB
// lower 3 bits
enum CANLOADTX_A_B_C {
    TXB0SIDH,           // 0x31
    TXB0D0,             // 0x36
    TXB1SIDH,           // 0x41
    TXB1D0,             // 0x46
    TXB2SIDH,           // 0x51
    TXB2D0
};

#define CAN_READ_RX_BUFF        0x90    // Set bits 1,2 for which RXB to read
// bits 1,2 or n,m. Where to start reading the buffer from
enum CANREADRX_N_M {
    RXB0SIDH,           // 0x61
    RXB0D0,             // 0x66
    RXB1SIDH,           // 0x71
    RXB1D0              // 0x76
};

struct CAN_Message {
    uint32_t    id;         // eye dee
    struct {
        uint8_t ext;        // Extended ID?
        uint8_t remote;     // Remote RX, or queued as RTR TX?
    } flags;
    uint8_t     len;        // Data field len in bytes, 0-8
    uint8_t     mbno;       // Mailbox Number
    uint8_t     data[8];    // Data
};


#define STDIDLEN            11
#define EXTIDLEN            29
#define EXT_ID_OFFSET       (EXTIDLEN - STDIDLEN)

#define MCP_MAILBOX_D0_OFFSET   5
enum MCP_Mailbox_Raw {
    XBnSIDH,
    XBnSIDL,
    XBnEID8,
    XBnEID0,
    XBnDLC,
    XBnD0,
    XBnD1,
    XBnD2,
    XBnD3,
    XBnD4,
    XBnD5,
    XBnD6,
    XBnD7
};




// CANCTRL and CANSTAT have many aliases

enum MCP25625_MEM_MAP {
    MMAP_RXF0SIDH,
    MMAP_RXF0SIDL,
    MMAP_RXF0EID8,
    MMAP_RXF0EID0,
    MMAP_RXF1SIDH,
    MMAP_RXF1SIDL,
    MMAP_RXF1EID8,
    MMAP_RXF1EID0,
    MMAP_RXF2SIDH,
    MMAP_RXF2SIDL,
    MMAP_RXF2EID8,
    MMAP_RXF2EID0,
    MMAP_BFPCTRL,
    MMAP_TXRTSCTRL,
    MMAP_CANSTAT_A0,
    MMAP_CANCTRL_A0,

    MMAP_RXF3SIDH,
    MMAP_RXF3SIDL,
    MMAP_RXF3EID8,
    MMAP_RXF3EID0,
    MMAP_RXF4SIDH,
    MMAP_RXF4SIDL,
    MMAP_RXF4EID8,
    MMAP_RXF4EID0,
    MMAP_RXF5SIDH,
    MMAP_RXF5SIDL,
    MMAP_RXF5EID8,
    MMAP_RXF5EID0,
    MMAP_TEC,
    MMAP_REC,
    MMAP_CANSTAT_A1,
    MMAP_CANCTRL_A1,

    MMAP_RXM0SIDH,
    MMAP_RXM0SIDL,
    MMAP_RXM0EID8,
    MMAP_RXM0EID0,
    MMAP_RXM1SIDH,
    MMAP_RXM1SIDL,
    MMAP_RXM1EID8,
    MMAP_RXM1EID0,
    MMAP_CNF3,
    MMAP_CNF2,
    MMAP_CNF1,
    MMAP_CANINTE,
    MMAP_CANINTF,
    MMAP_EFLG,
    MMAP_CANSTAT_A2,
    MMAP_CANCTRL_A2,

    MMAP_TXB0CTRL,
    MMAP_TXB0SIDH,
    MMAP_TXB0SIDL,
    MMAP_TXB0EID8,
    MMAP_TXB0EID0,
    MMAP_TXB0DLC,
    MMAP_TXB0D0,
    MMAP_TXB0D1,
    MMAP_TXB0D2,
    MMAP_TXB0D3,
    MMAP_TXB0D4,
    MMAP_TXB0D5,
    MMAP_TXB0D6,
    MMAP_TXB0D7,
    MMAP_CANSTAT_A3,
    MMAP_CANCTRL_A3,

    MMAP_TXB1CTRL,
    MMAP_TXB1SIDH,
    MMAP_TXB1SIDL,
    MMAP_TXB1EID8,
    MMAP_TXB1EID0,
    MMAP_TXB1DLC,
    MMAP_TXB1D0,
    MMAP_TXB1D1,
    MMAP_TXB1D2,
    MMAP_TXB1D3,
    MMAP_TXB1D4,
    MMAP_TXB1D5,
    MMAP_TXB1D6,
    MMAP_TXB1D7,
    MMAP_CANSTAT_A4,
    MMAP_CANCTRL_A4,

    MMAP_TXB2CTRL,
    MMAP_TXB2SIDH,
    MMAP_TXB2SIDL,
    MMAP_TXB2EID8,
    MMAP_TXB2EID0,
    MMAP_TXB2DLC,
    MMAP_TXB2D0,
    MMAP_TXB2D1,
    MMAP_TXB2D2,
    MMAP_TXB2D3,
    MMAP_TXB2D4,
    MMAP_TXB2D5,
    MMAP_TXB2D6,
    MMAP_TXB2D7,
    MMAP_CANSTAT_A5,
    MMAP_CANCTRL_A5,
    
    MMAP_RXB0CTRL,
    MMAP_RXB0SIDH,
    MMAP_RXB0SIDL,
    MMAP_RXB0EID8,
    MMAP_RXB0EID0,
    MMAP_RXB0DLC,
    MMAP_RXB0D0,
    MMAP_RXB0D1,
    MMAP_RXB0D2,
    MMAP_RXB0D3,
    MMAP_RXB0D4,
    MMAP_RXB0D5,
    MMAP_RXB0D6,
    MMAP_RXB0D7,
    MMAP_CANSTAT_A6,
    MMAP_CANCTRL_A6,

    MMAP_RXB1CTRL,
    MMAP_RXB1SIDH,
    MMAP_RXB1SIDL,
    MMAP_RXB1EID8,
    MMAP_RXB1EID0,
    MMAP_RXB1DLC,
    MMAP_RXB1D0,
    MMAP_RXB1D1,
    MMAP_RXB1D2,
    MMAP_RXB1D3,
    MMAP_RXB1D4,
    MMAP_RXB1D5,
    MMAP_RXB1D6,
    MMAP_RXB1D7,
    MMAP_CANSTAT_A7,
    MMAP_CANCTRL_A7
};


#endif

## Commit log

2023-12-28 Waffle Mini file dump
    [Waffle_Mini_v0.kicad_pcb, Waffle_Mini_v0.kicad_sch]
2023-12-28 Layout kinda done v0 waffle mini
    [Waffle_Mini_v0.kicad_pcb, Waffle_Mini_v0.kicad_sch]
2023-12-31 Curly added :)
    [Curly_Mini_v0.kicad_pcb, Curly_Mini_v0.kicad_sch, MCP25625T-E_ML.step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]
2023-12-31 Curly partially done
    [Curly_Mini_v0.kicad_pcb, Curly_Mini_v0.kicad_sch]
2024-01-01 Curly Mini almost done :)
    [Curly_Mini_v0.kicad_pcb, Curly_Mini_v0.kicad_sch]
2024-01-01 Curly Mini almost done (again) :)
    [Curly_Mini_v0.kicad_pcb, Curly_Mini_v0.kicad_sch]
2024-01-01 Curly Mini RS232 completed
    [Curly_Mini_v0.kicad_pcb, Curly_Mini_v0.kicad_sch]
2024-01-01 Curly Mini Prelim layout done
    [Curly_Mini_v0.kicad_pcb, Curly_Mini_v0.kicad_sch]
2024-01-02 Final v0 revision made, JLC fab files provided. Castellated holes are ultra expensive, moved to 2 sided edge connect
    [Curly_Mini_v0-B_Cu.gbr, Curly_Mini_v0-B_Mask.gbr, Curly_Mini_v0-B_Paste.gbr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]
2024-01-13 Blinky works on Curly :) Added CAN transceiver to Waffle
    [Waffle_Mini_v0-B_Cu.gbr, Waffle_Mini_v0-B_Mask.gbr, Waffle_Mini_v0-B_Paste.gbr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]
2024-01-13 Added USB ESD Protection, USB Boot button - Curly
    [Curly_Mini_v0.kicad_pcb, Curly_Mini_v0.kicad_sch]
2024-01-13 Small cleanup on Curly
    [Curly_Mini_v0.kicad_pcb]
